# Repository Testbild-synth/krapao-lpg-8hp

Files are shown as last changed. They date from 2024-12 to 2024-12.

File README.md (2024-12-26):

# Voxmachina Krapao Resonant Low Pass Gate - now in 8HP
This repository contains the files for a narrower version of the great 
[Krapao low pass gate](https://www.youtube.com/watch?v=gdqPUZgIWGM&t=87s) module from voxmachina.

I would say my version is more of a bootleg/edit more than actually changing much here.

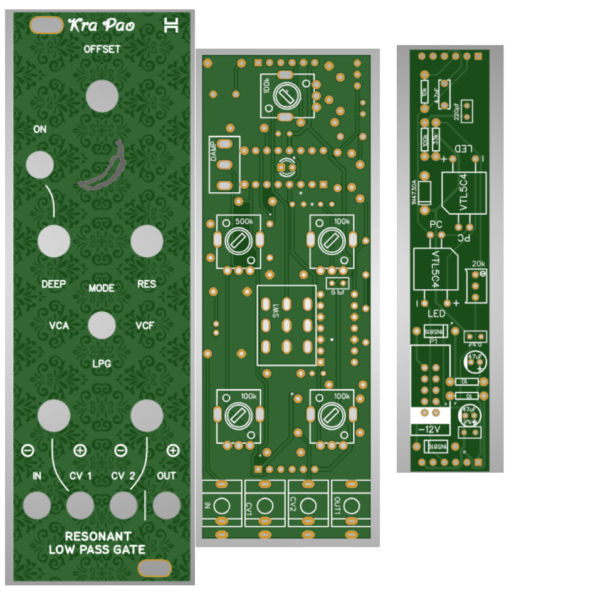
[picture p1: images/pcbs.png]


## Status: confirmed working!

## Hardware and ordering
The repo has three gerbers, one is the panel, one is the control pcb, one is the "main pcb" which basically 
only contains the vactrols. Just order one of each at a pcb service of your choice (I use jlcpcb.com).

BOM is the same as original krapao, I have a csv file but it'S not very tidy. All pots are R09k type (I make the holes
bigger because the chinese knock offs have bigger legs) all jacks are thonkiconn.

Instead of ordering VTL5C3 vactrols (which are expensive) I would recommend making your own using
a simple LED, some shrink tubing and an LDR. There are a ton of tutorials out there just google DIY vactrol.

the big switch is a 3dpt, somethings like [this](https://www.musikding.de/Toggleswitch-3PDT-on-off-on). There are a wide variety,
idk which one is the best but ideally it should be the lowest you can get (because it does stand out a bit further than the thonkiconn jacks which makes the whole module
tilt at a slight angle). Not sure how voxmachina does this but on mine it's still fine and not that noticable in the final module.
the big 3dpt is ON-OFF-ON, the smaller spdt is ON-ON.

## Build
Since the build is a bit crammy on 8hp there are a few places where you have to think about what order you solder things in.
Most notably the LED in the front that is on the backside of a TL074. Nothing horrible, just take it slow.

Earlier versions had the problem of things on the control pcb and the vactrol pcb sticking out and being in the
way of each other. This should be resolved by now.

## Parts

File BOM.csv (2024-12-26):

 |  | Control board
ID | Name | Designator | Footprint | Quantity | Manufacturer Part | Manufacturer
1 | 1nf | C1 | CAP FILM KEMET 2.5*7.2 | 1 | SMR5102J50J01 | kemet
2 | 1uF | C2 | CAP-TH_BD5.0-P2.00-D0.8-FD | 1 | 47uF 16V 5*5 | ValuePro
3 | 22pf | C3 | RAD-0.1 | 1
4 | 2nf | C4 | CAP FILM KEMET 2.5*7.2 | 1 | SMR5102J50J01 | kemet
5 | 0.1uf | C5,C6,C7,C8 | RAD-0.1 | 4
6 | 1uF | C9 | RAD-0.1 | 1
7 | CV 1 IN, CV2 IN, Audio IN, Audio out | CV1, CV2, IN, OUT1 | THONKICONN | 4 | PJ-301BM | Tayda Electronics
8 | 100k | CV1_ADJ,CV2_ADJ,OFFSET_POT,RES_POT | R09K Potentiometer | 4
10 | 1N4148 | D1 | DO-35_BD2.0-L4.0-P8.00-D0.5-FD | 1 | 1N4148 | SEMTECH
11 | 500k | DEEP_POT | R09K Potentiometer | 1
12 | HTOP | H1 | HDR-F-2.54_1X6 | 1
13 | HBOT | H2 | HDR-F-2.54_1X6 | 1
15 | LED | LED1 | LED_LED3MM | 1
16 | 10k | LED_ADJ | TRIMPOT | 1
18 | 1k | R1 | AXIAL-0.3EZ | 1
19 | 4M7 | R2 | AXIAL-0.3EZ | 1
20 | 10k | R3,R10,R19 | AXIAL-0.3EZ | 3
21 | 15k | R4,R5 | AXIAL-0.3EZ | 2
22 | 100k | R6,R7,R9,R11,R15,R16,R17,R21,R22,R24 | AXIAL-0.3EZ | 10
23 | 2k2 | R8 | AXIAL-0.3EZ | 1
24 | 150k | R14 | AXIAL-0.3EZ | 1
25 | 470k | R18 | AXIAL-0.3EZ | 1
26 | 470 | R23 | AXIAL-0.3EZ | 1
27 | MODE | SW1 | (TAYDA) MINI TOGGLE SWITCH 3PDT ON-OFF-ON SKU A-1955 | 1 |  | Tayda Electronics
28 | DAMP | SW2 | TAYDA SPDT TOGGLE SWITCH A-3670_LARGERHOLES | 1
29 | TL084 | U1 | DIP-14 | 1 | TL074
30 | TL074 | U2 | DIP-14 | 1 | TL074
 |  | Vactrol board
ID | Name | Designator | Footprint | Quantity | Manufacturer Part | Manufacturer
1 | 220pf | C1 | RAD-0.1 | 1
2 | 47uF | C3,C5 | CAP-TH_BD5.0-P2.00-D0.8-FD | 2 | 47uF 16V 5*5 | ValuePro
3 | 0.1uf | C4,C6 | RAD-0.1 | 2
4 | 4.7nF | C8 | CAP-TH_L6.5-W2.5-P5.00-D1.0 | 1 | Calibration capacitor4.7nf 5% 100V | ReliaPro
5 | 1N4730A | D1 | DO-41 | 1
6 | 1N5819 | D2,D3 | DO-41_BD2.4-L4.7-P8.70-D0.9-RD | 2 | 1N5819G | ON Semicon
7 | HTOP | H1 | HDR-F-2.54_1X6 | 1
8 | HBOT | H2 | HDR-F-2.54_1X6 | 1
9 | POWER | P1 | EURORACK SHROUDED POWER 10 PIN | 1 | New SchematicLib
10 | 33k | R1 | AXIAL-0.3EZ | 1
11 | 100k | R2 | AXIAL-0.3EZ | 1
12 | 10k | R3 | AXIAL-0.3EZ | 1
13 | 10 | R4,R5 | AXIAL-0.3EZ | 2
14 | 20k | TM1 | TRIMPOT | 1
15 | VTL5C4 | U1,U2 | VTL5C4 | 2

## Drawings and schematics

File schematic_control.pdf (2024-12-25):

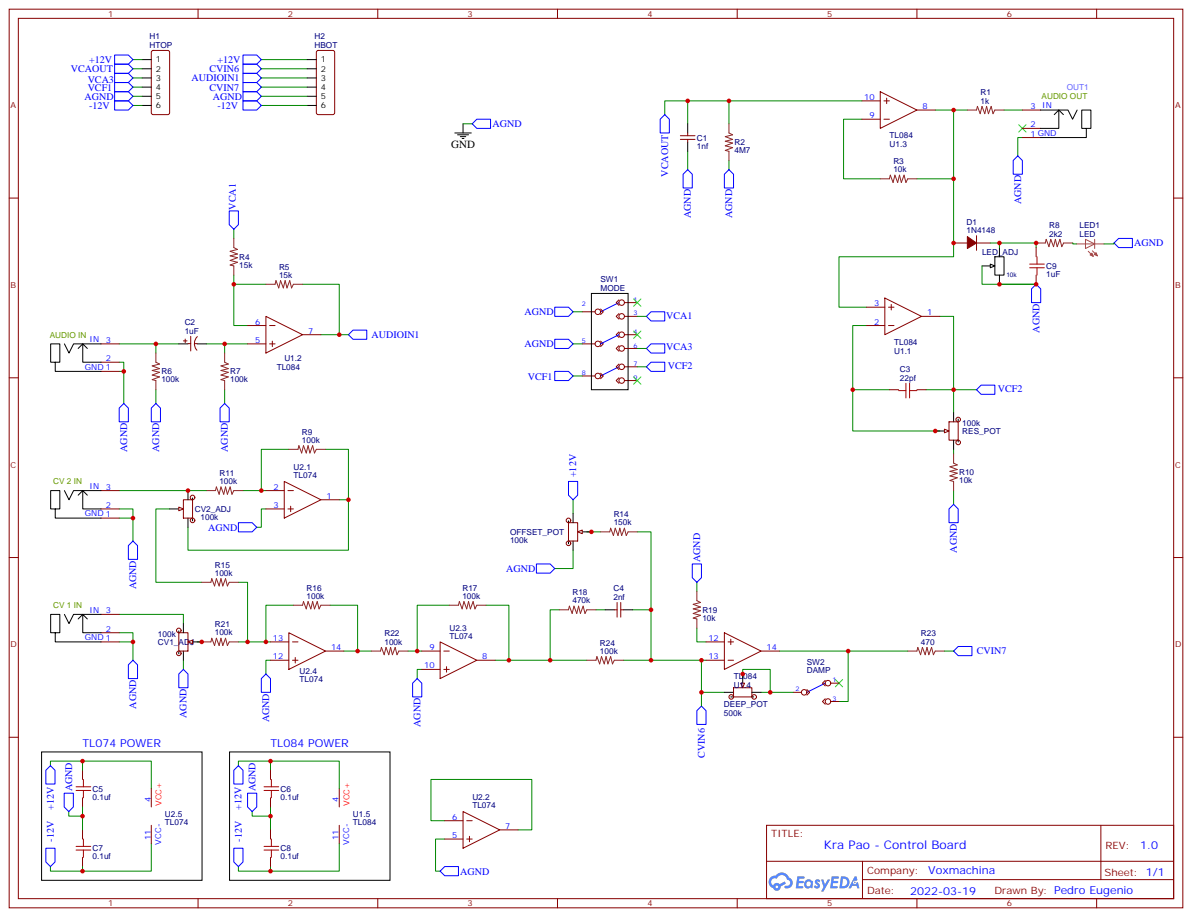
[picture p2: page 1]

Drawn By: Pedro Eugenio

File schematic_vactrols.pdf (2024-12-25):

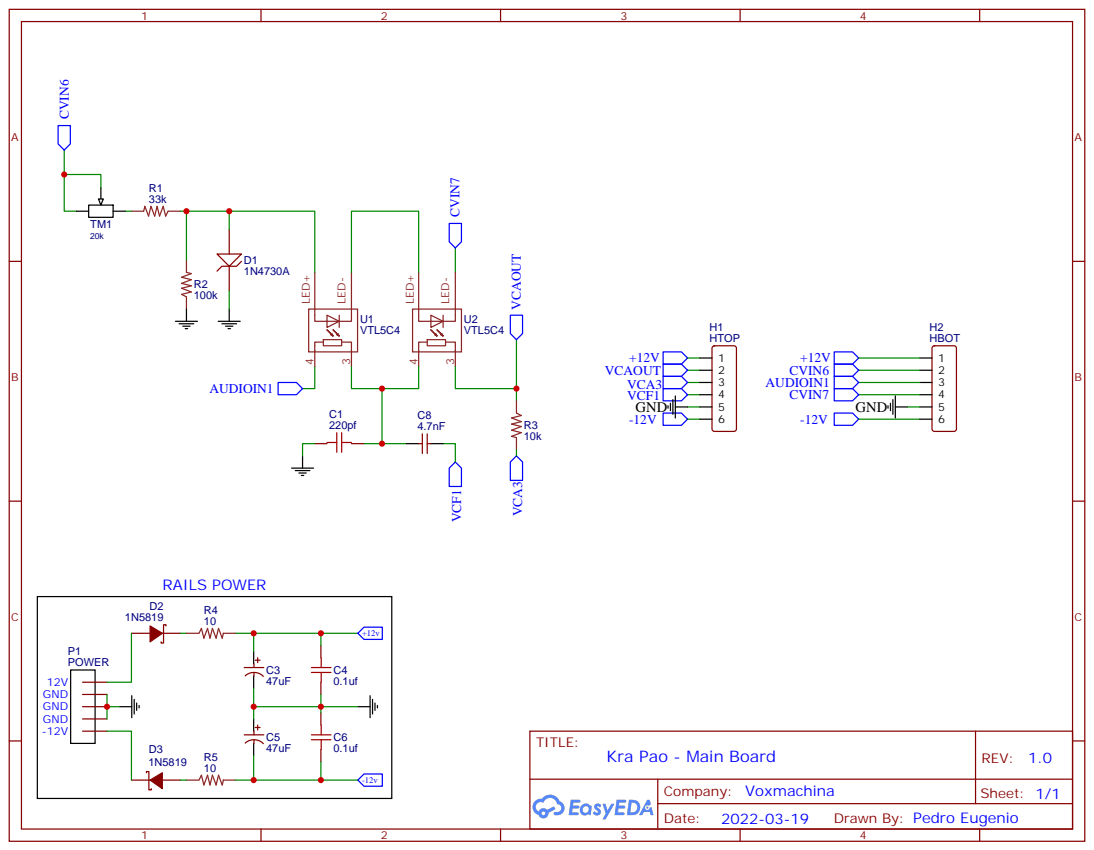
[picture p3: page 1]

Drawn By: Pedro Eugenio

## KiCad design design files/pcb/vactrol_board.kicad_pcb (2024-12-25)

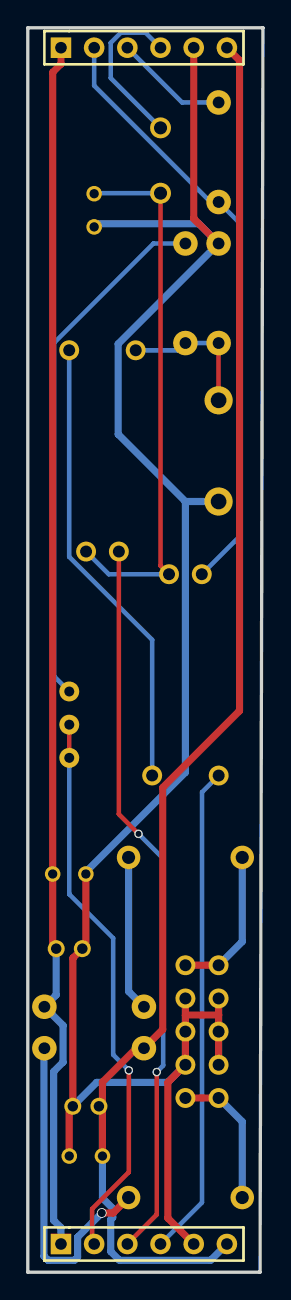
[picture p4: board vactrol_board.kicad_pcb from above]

Board: 2 copper layers, 18.0 x 95.2 mm, 20 parts (0 on the bottom side), 17 nets.

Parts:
C1: 220pf; RAD-0.1
C3, C5: 47uF; CAP-TH_BD5.0-P2.00-D0.8-FD
C4, C6: 0.1uf; RAD-0.1
C8: 4.7nF; CAP-TH_L6.5-W2.5-P5.00-D1.0
D1: 1N4730A; DO-41
D2, D3: 1N5819; DO-41_BD2.4-L4.7-P8.70-D0.9-RD
H1: TOP; HDR-F-2.54_1X6
H2: BOT; HDR-F-2.54_1X6
P1: POWER; EURORACK SHROUDED POWER 10 PIN
R1: 33k; AXIAL-0.3EZ
R2: 100k; AXIAL-0.3EZ
R3: 10k; AXIAL-0.3EZ
R4, R5: 10; AXIAL-0.3EZ
TM1: 20k; TRIMPOT
U1, U2: VTL5C4

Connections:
+12V: C3.1, C4.2, H1.1, H2.1, R4.2
-12V: C5.2, C6.1, H1.6, H2.6, R5.2
AUDIOIN1: H2.3, U1.4
CVIN6: H2.2, TM1.2, TM1.3
CVIN7: H2.4, U2.1
D2_1: D2.1, R4.1
D3_2: D3.2, R5.1
GND: C1.2, C3.2, C4.1, C5.1, C6.2, D1.2, H1.5, H2.5, P1.2, P1.3, P1.4, R2.1
P1_1: D2.2, P1.1
P1_5: D3.1, P1.5
R1_2: R1.2, TM1.1
U1_2: D1.1, R1.1, R2.2, U1.2
U2_2: U1.1, U2.2
U2_4: C1.1, C8.1, U1.3, U2.4
VCA3: H1.3, R3.2
VCAOUT: H1.2, R3.1, U2.3
VCF1: C8.2, H1.4

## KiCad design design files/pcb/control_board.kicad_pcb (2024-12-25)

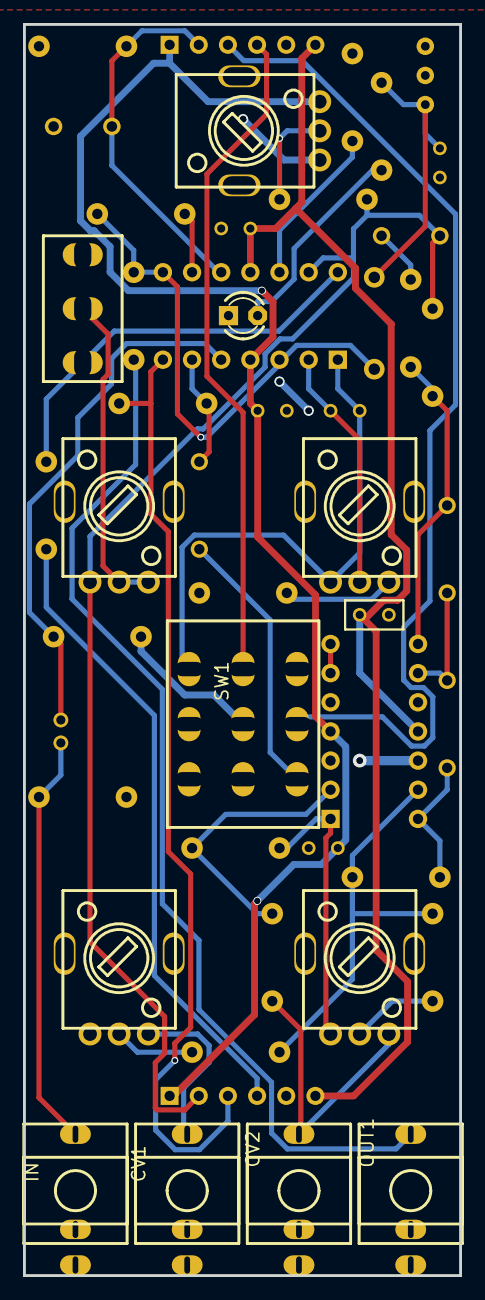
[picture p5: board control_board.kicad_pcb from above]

Board: 2 copper layers, 38.0 x 109.0 mm, 48 parts (0 on the bottom side), 37 nets.

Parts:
C1: 1nf; CAP FILM KEMET 2.5*7.2
C2: 1uF; CAP-TH_BD5.0-P2.00-D0.8-FD
C3: 22pf; RAD-0.1
C4: 2nf; CAP FILM KEMET 2.5*7.2
C5, C6, C7, C8: 0.1uf; RAD-0.1
C9: 1uF; RAD-0.1
CV1: CV 1 IN; THONKICONN
CV1_ADJ, CV2_ADJ: 100k; R09-5KΩ
CV2: CV 2 IN; THONKICONN
D1: 1N4148; DO-35_BD2.0-L4.0-P8.00-D0.5-FD
DEEP_POT: 500k; R09-5KΩ
H1: HTOP; HDR-F-2.54_1X6
H2: HBOT; HDR-F-2.54_1X6
IN: AUDIO IN; THONKICONN
LED1: LED; LED_LED3MM
LED_ADJ: 10k; TRIMPOT
OFFSET_POT: 100k; R09-5KΩ
OUT1: AUDIO OUT; THONKICONN
R1: 1k; AXIAL-0.3EZ
R2: 4M7; AXIAL-0.3EZ
R3, R10, R19: 10k; AXIAL-0.3EZ
R4, R5: 15k; AXIAL-0.3EZ
R6, R7, R9, R11, R15, R16, R17, R21, R22, R24: 100k; AXIAL-0.3EZ
R8: 2k2; AXIAL-0.3EZ
R14: 150k; AXIAL-0.3EZ
R18: 470k; AXIAL-0.3EZ
R23: 470; AXIAL-0.3EZ
RES_POT: 100k; R09-5KΩ
SW1: MODE; (TAYDA) MINI TOGGLE SWITCH 3PDT ON-ON SKU A-1955
SW2: DAMP; TAYDA SPDT TOGGLE SWITCH A-3670_LARGERHOLES
U1: TL084; DIP-14
U2: TL074; DIP-14

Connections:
+12V: C5.2, C6.2, H1.1, H2.1, OFFSET_POT.3, U1.4, U2.4
-12V: C7.1, C8.1, H1.6, H2.6, U1.11, U2.11
AGND: C1.1, C5.1, C6.1, C7.2, C8.2, C9.1, CV1.1, CV1.2, CV1_ADJ.1, CV2.1, CV2.2, H1.5, H2.5, IN.1, IN.2, LED1.-, LED_ADJ.2, LED_ADJ.3, OFFSET_POT.1, OUT1.1, R2.2, R6.2, R7.2, R10.2, R19.1, SW1.2, SW1.5, U2.3, U2.5, U2.10, U2.12
AUDIOIN1: H2.3, R5.1, U1.7
C2_1: C2.1, IN.3, R6.1
C3_1: C3.1, RES_POT.2, U1.2
CV1_3: CV1.3, CV1_ADJ.3
CVIN6: C4.1, DEEP_POT.1, H2.2, R14.1, R24.1, U1.13
CVIN7: H2.4, R23.1
D1_2: C9.2, D1.2, LED_ADJ.1, R8.2
LED1_+: LED1.+, R8.1
OUT1_3: OUT1.3, R1.1
R1_2: D1.1, R1.2, R3.1, U1.3, U1.8
R3_2: R3.2, U1.9
R4_2: R4.2, R5.2, U1.6
R7_1: C2.2, R7.1, U1.5
R9_1: CV2_ADJ.1, R9.1, U2.1
R9_2: R9.2, R11.1, U2.2
R10_1: R10.1, RES_POT.3
R11_2: CV2.3, CV2_ADJ.3, R11.2
R14_2: OFFSET_POT.2, R14.2
R15_1: R15.1, R16.2, R21.1, U2.13
R15_2: CV2_ADJ.2, R15.2
R17_2: R17.2, R22.1, U2.9
R18_1: C4.2, R18.1
R18_2: R17.1, R18.2, R24.2, U2.8
R19_2: R19.2, U1.12
R21_2: CV1_ADJ.2, R21.2
R22_2: R16.1, R22.2, U2.14
R23_2: R23.2, SW2.3, U1.14
SW2_2: DEEP_POT.2, DEEP_POT.3, SW2.2
U2_6: U2.6, U2.7
VCA1: R4.1, SW1.3
VCA3: H1.3, SW1.6
VCAOUT: C1.2, H1.2, R2.1, U1.10
VCF1: H1.4, SW1.8
VCF2: C3.2, RES_POT.1, SW1.7, U1.1

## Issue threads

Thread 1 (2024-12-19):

might this happen

K-Teck-Dave, 2024-12-19:
i would love it if you could make this happen...

best

Testbild-synth, 2024-12-25:
hey i finished this like 3 months ago just forgot to upload the files, will do today

Testbild-synth, 2024-12-25:
all the files should be there now, happy holidays :)

K-Teck-Dave, 2024-12-26:
thank you... i've built several of the VoxMachina ones, the switch is too tall in those and in the AISynthesis LPG aswell. In your BOM you list the 3PDT Switch as ON-ON - it should read ON-OFF-ON. I've ordered the boards, looking forward...

Testbild-synth, 2024-12-26:
I clarified the switch choices in both the BOM and the readme, thank you for notifying me!

Closed 2024-12-25.

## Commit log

2024-12-25 initial file upload
    [BOM.csv, control_board.kicad_pcb, krapao_8hp.kicad_pcb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]
2024-12-26 clarified switch choice in BOM
    [BOM.csv]
